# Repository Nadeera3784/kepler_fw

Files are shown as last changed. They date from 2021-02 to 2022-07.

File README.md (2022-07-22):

# F91 Kepler

<p align="center">
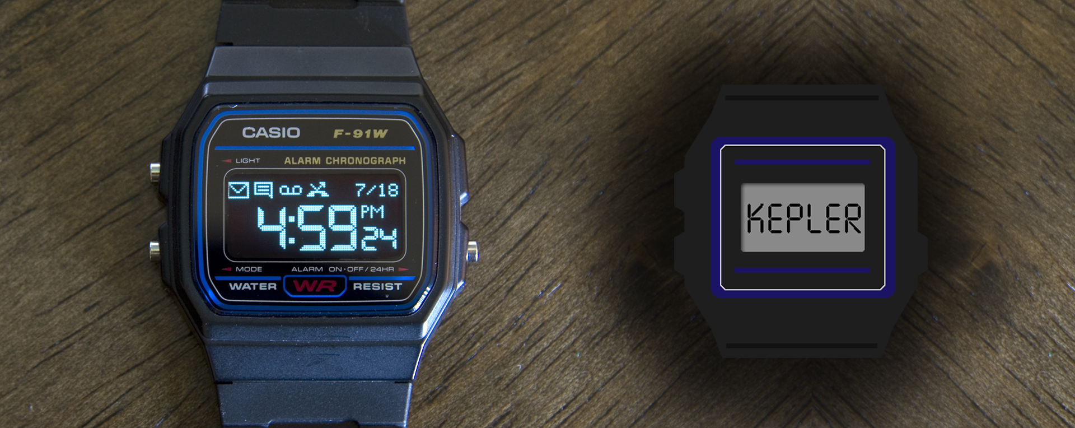
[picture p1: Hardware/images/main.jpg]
  
</p>

The F91 Kepler is complete redesign of the classic Casio F91W watch. This project completely replaces the original internals of the watch only keeping the original case and adding an OLED display and a bluetooth capable MCU.

This repo contains all the firmware, hardware, and completely unfinished software (phone app) ;).

## As of 7/18/22 the current state of the project is:
- Bluetooth capable and supports several calls.
- Only operates through bluetooth diagnostic apps such as nRF Connect.
- Full screen notifications for calls/texts.
- Notifications bar.
- Only one button currently supported to wake screen.
- Battery life of roughly 15 days with waking screen several times a day.

## To-do / improvements:
- Create phone app to handle sending ble calls automatically.
- Add ability to set time through buttons.
- Add sound capabilities. 
- Improve battery life and effiency.
- Improve programming jig (make it easier to do without having to completely dismantle)
- Make rechargeable

### At this point (read more like a year ago) I am burnt out from this project and now I figured to open it up and hopefully more people can be involved.

<p align="center">
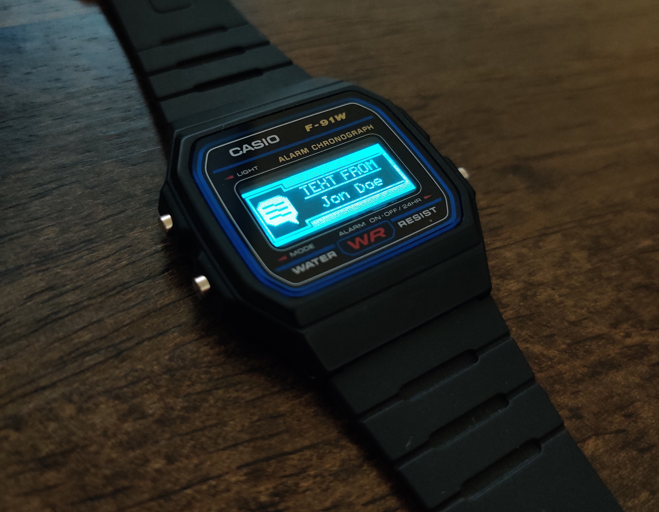
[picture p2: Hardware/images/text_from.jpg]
  
</p>

### Contact
devPegor@gmail.com

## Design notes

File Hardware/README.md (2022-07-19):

# Kepler HW

Found here are the PCB files as well as 3D parts that were made to accommodate this project.

## Main PCB
The PCB was designed using [Diptrace](https://diptrace.com/). The free version was enough for this entire project. The design is not extremely complicated and was based off the development board and design requirements mentioned in the CC2640 Datasheet.

My first design for the board used FPC connectors for the display (4 pin) as well as one for programming/debugging (11 pin). This was later changed to use the Molex board to board connector for the display and small connection points across the PCB for programming/debugging. These changes were made to save room and make it easier to not have to solder and unsolder an FPC connector for programming/debugging. The connection points are hard to see in the real images, but are visible in the render seen in Figure 3 below. The PCB is only two layers and was printed by [OSHPark](https://oshpark.com/) at 0.8mm. This thickness was a little thicker than the original 0.6mm board, but at the price and speed of the service it couldn't be beat. Yes, you can get 0.6mm boards from services such as PCB Way for cheaper, but the shipping costs a ton (at least at this time) and takes forever. The TI design requirements also suggest an 0.8mm board if memory serves me right...

<p align="center">
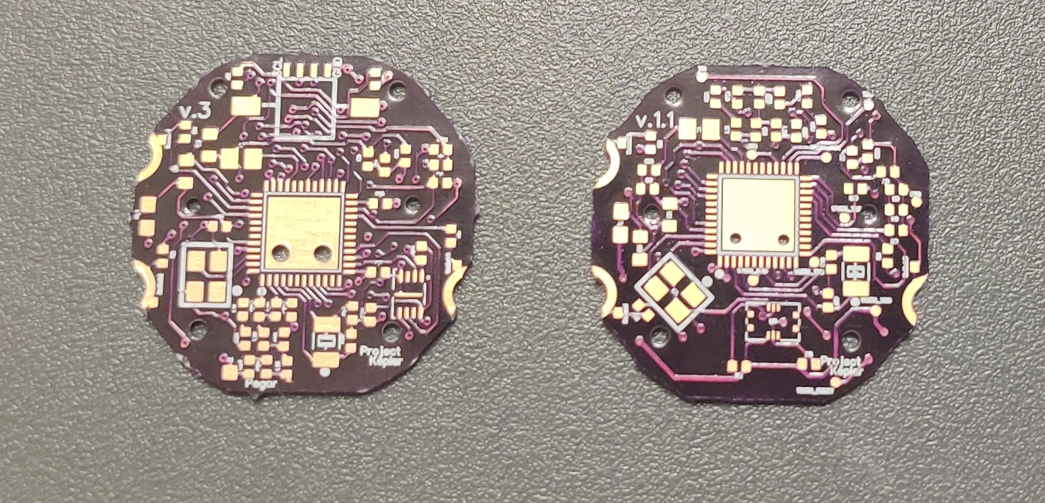
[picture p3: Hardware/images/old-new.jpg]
First & New Design
  
  <br><b>Figure 1</b>: First design on the left and new design on the right.
</p>
<p align="center">
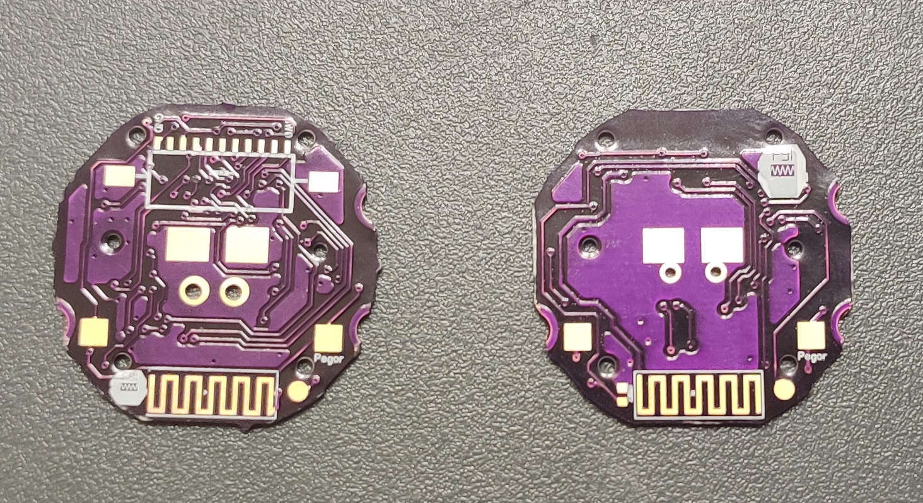
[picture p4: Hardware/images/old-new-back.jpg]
Back of First & New Design
  
  <br><b>Figure 2</b>: Back of first and new design.
</p>

<p align="center">
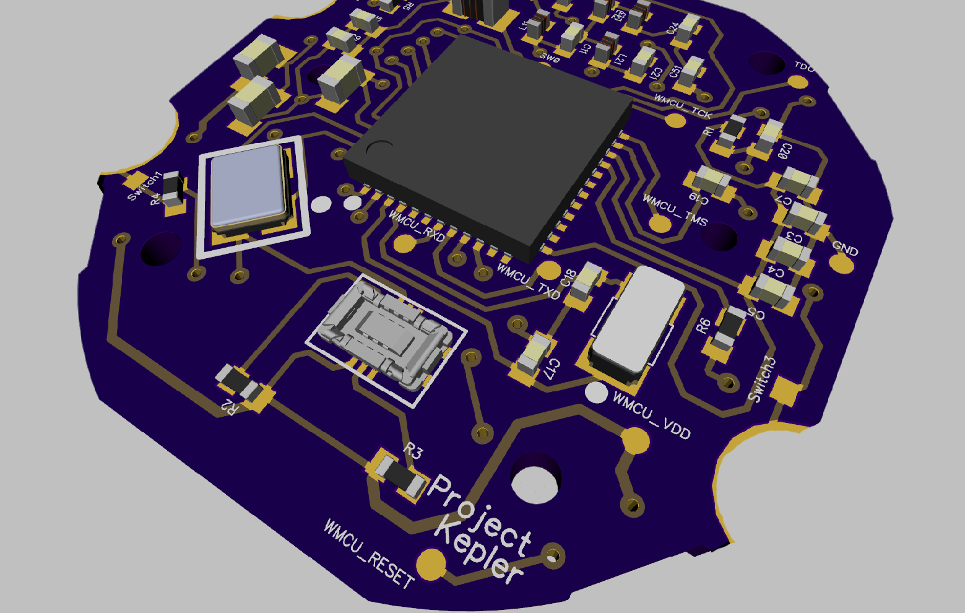
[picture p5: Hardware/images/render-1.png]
PCB Render
  
  <br><b>Figure 3</b>: Render of PCB with connection points visible.
</p>

## Display Adapter
The display adapter was designed to take the 28 pins of the SSD1306 OLED display and bring them down to an easy to use I2C interface. My original design was intended to pair with the FPC connector on the main PCB, but it was too bulky. The second design is much slimmer, easy to manage, and uses a molex board to board connector which so far has worked much better than the FPC connection. One thing to note is that it was an absolute pain to solder those molex connections by hand. 
<p align="center">
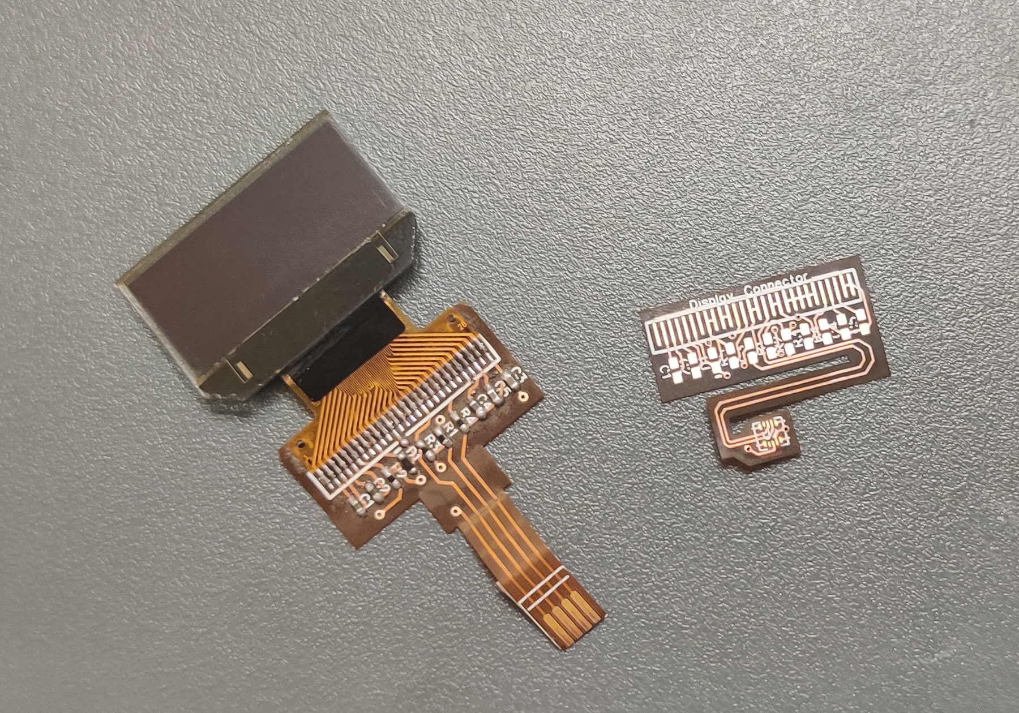
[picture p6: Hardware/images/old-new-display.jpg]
First & New Display Design
  
  <br><b>Figure 4</b>: First display adapter and second design.
</p>

## 3D Parts

### Movement Holder
The original goal for this project was to only change the PCB and display, but the further I got into it the more I realized it's going to be a pain in the ass to use the original movement holder. I tried multiple methods of sanding down and cutting out bits of it, see Figure 5, but it was just a mess and frustrating to work with, so I invested in a resin printer (Hurray, more shit to learn). Once I got a feel for [Fusion 360](https://www.autodesk.com/products/fusion-360), I designed a new movement holder that made life much easier. The new movement holder hugged the PCB perfectly and I was still able to use the original battery clamp, see Figure 9, which made it look so nice! Looking at Figure 6 it's clear how much room I gained from moving away from the original holder. The only part now that was still a little "janky" was that I had to sand down the edges of the SSD1306 Display to make it fit in the case. You can see the sanded rough edges in Figure 8. It's not terrible and much better than murdering the original case, with these changes the case and caseback remained original!

<p align="center">
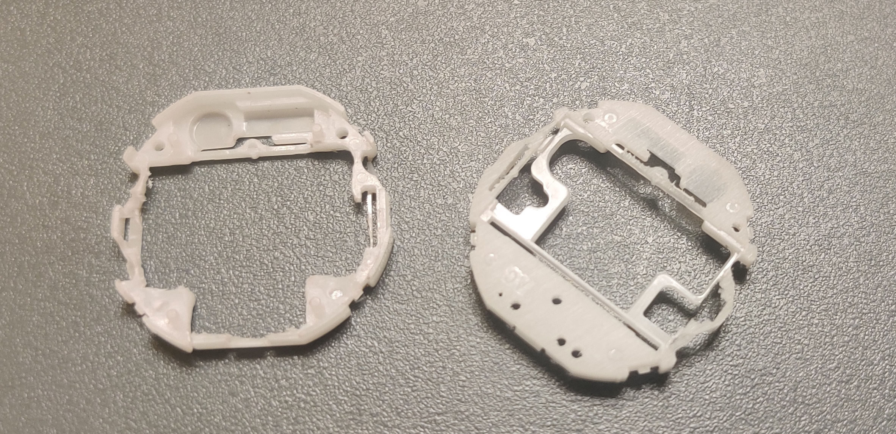
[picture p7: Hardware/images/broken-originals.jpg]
Broken Original Movement Holders
  
  <br><b>Figure 5</b>: Original movement holders.
</p>
<p align="center">
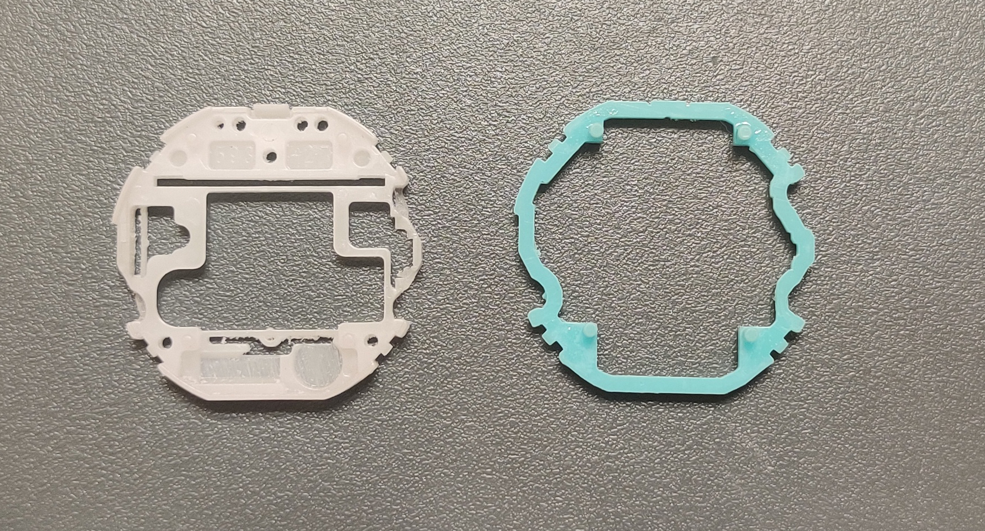
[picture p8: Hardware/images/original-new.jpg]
Original and New Movement Holder
  
  <br><b>Figure 6</b>: Original movement holder on the left and new one on the right.
</p>
<p align="center">
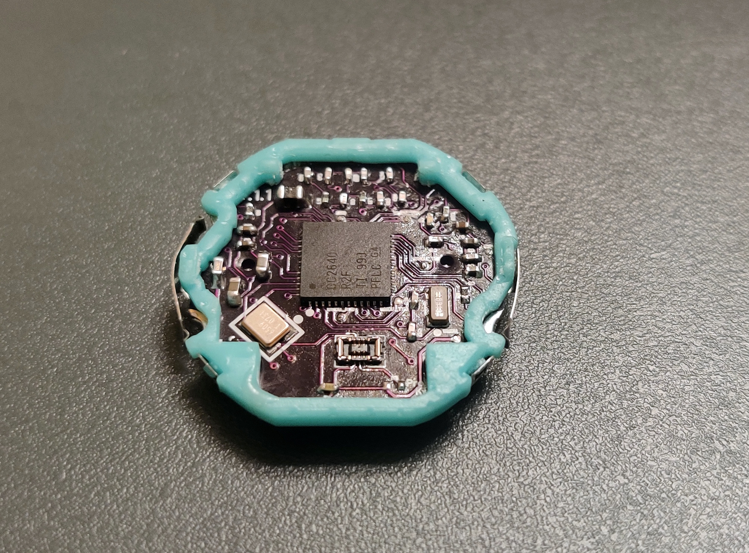
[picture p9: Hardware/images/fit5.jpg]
PCB in Movement Holder
  
  <br><b>Figure 7</b>: PCB sitting perfectly within new movement holder.
</p>
<p align="center">
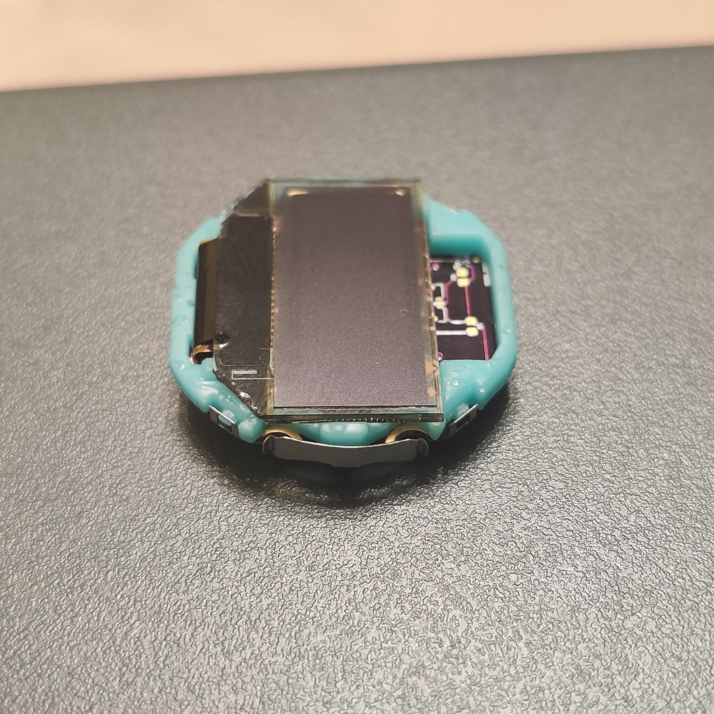
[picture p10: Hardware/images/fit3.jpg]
Display in movement holder
  
  <br><b>Figure 8</b>: Display sitting in new movement holder.
</p>
<p align="center">
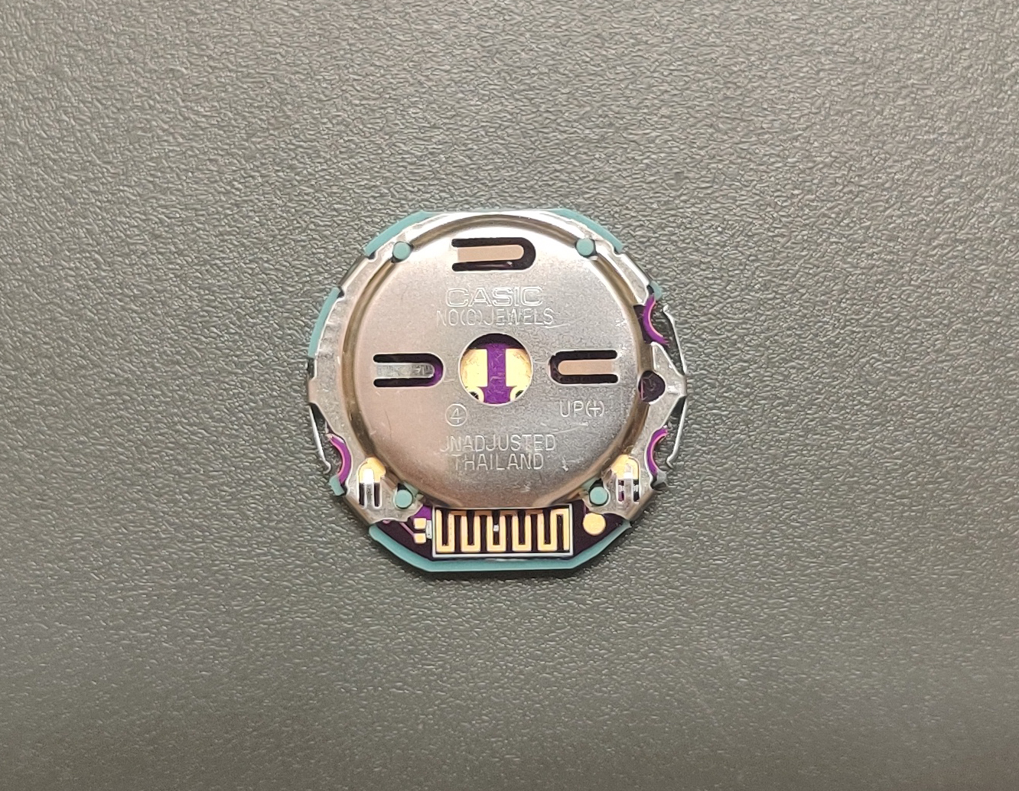
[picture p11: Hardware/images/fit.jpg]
Back of new movement holder
  
  <br><b>Figure 9</b>: Original battery clamp on the new PCB & movement holder.
</p>
<p align="center">
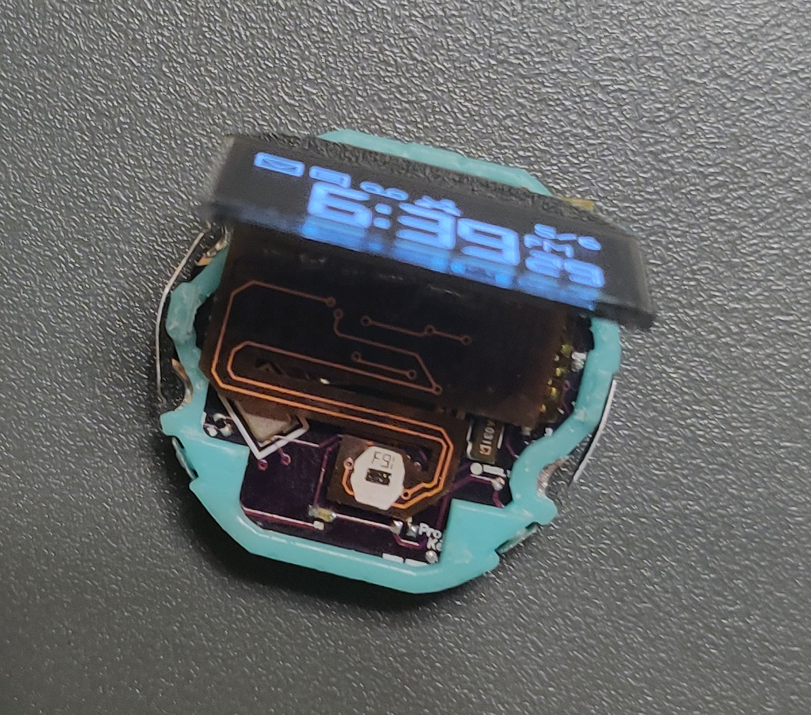
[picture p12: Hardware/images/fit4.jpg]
Display with new movement holder
  
  <br><b>Figure 10</b>: Display connection to the PCB.
</p>
<p align="center">
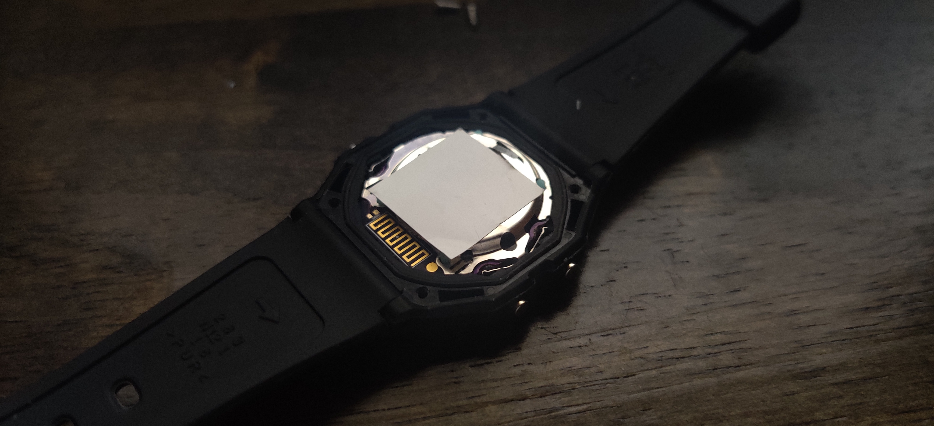
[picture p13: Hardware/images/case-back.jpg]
Case back
  
  <br><b>Figure 11</b>: Perfect fit of the new movement.
</p>

<p align="center">
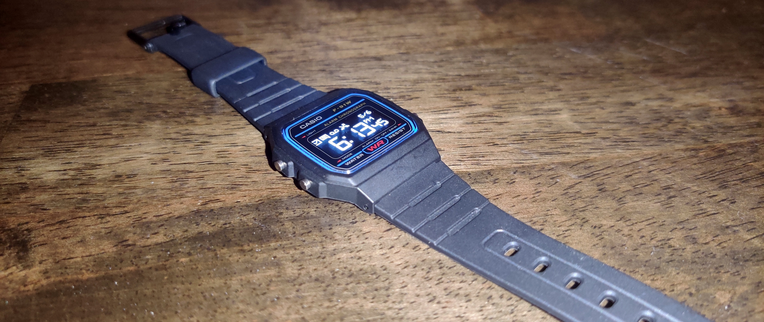
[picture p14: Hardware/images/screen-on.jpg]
Case
  
  <br><b>Figure 12</b>: Completed Build.
</p>

### Programming Jig
Moving away from the 11 pin FPC connector that was on my old design to the new 10 connection points on the PCB meant I needed a jig that can be easily used to program/debug the PCB. My original plan was to use acrylic sheets and dremel some holes in it which would house some tiny pogo pins, but now that I had my hands on a resin printer I designed a jig that can save me a ton of time and look way better than cutting acrylic by hand. The design I came up with can bee seen in Figure 13. It used some [very small spring loaded pogo pings](https://www.amazon.com/gp/product/B08NSKWJTQ/ref=ppx_yo_dt_b_asin_title_o05_s00?ie=UTF8&psc=1) that press against the connection points on the PCB as seen in Figures 14 & 15. This programming jig easily paired with the TI Launchpad and I was able to program the watch from there.

<p align="center">
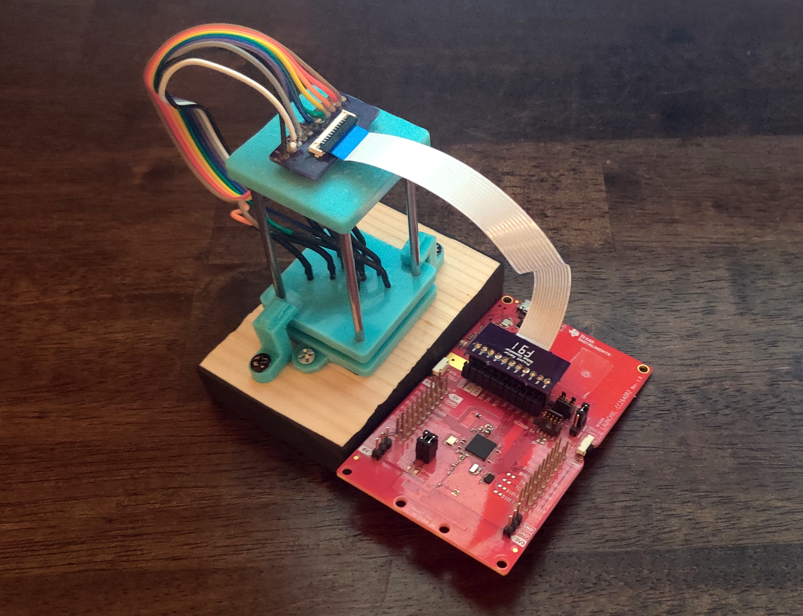
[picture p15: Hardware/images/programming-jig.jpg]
Programming Jig
  
  <br><b>Figure 13</b>: Jig used to program the PCB.
</p>
<p align="center">
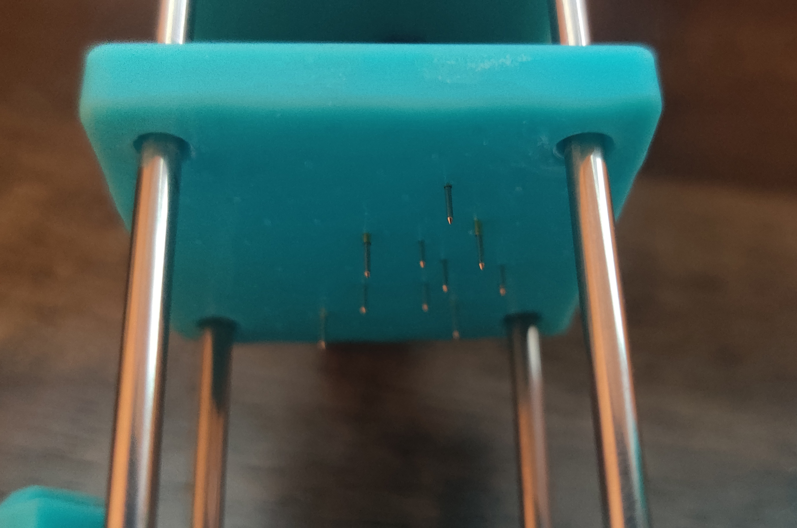
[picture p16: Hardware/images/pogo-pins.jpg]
Pogo pins
  
  <br><b>Figure 14</b>: Tiny spring loaded pogo pins that make the connection to the PCB.
</p>
<p align="center">
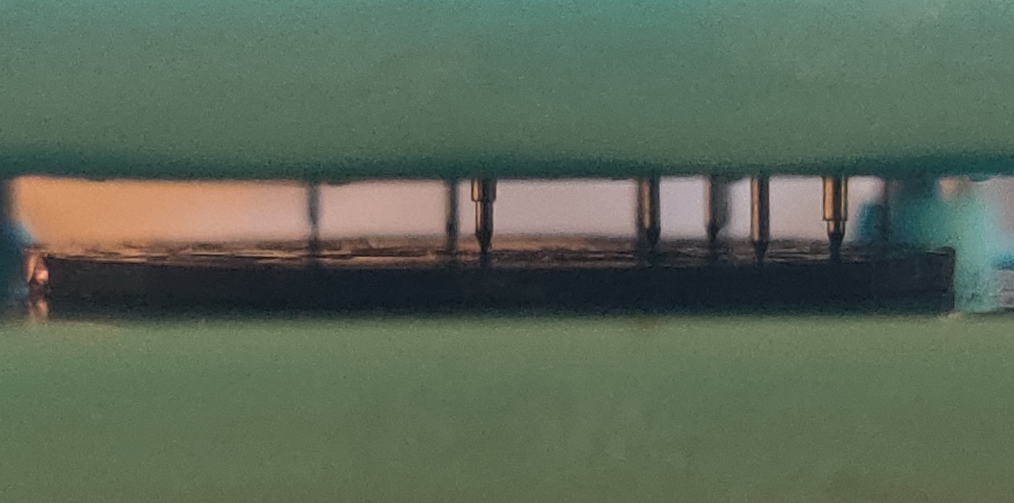
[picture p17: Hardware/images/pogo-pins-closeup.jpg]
Pogo pins
  
  <br><b>Figure 15</b>: Close up of the pogo pins in action.
</p>

## Parts & References
- [SSD1306 0.83" OLED Display](https://www.buydisplay.com/0-83-inch-oled-display-module-spi-ssd1306-controller-blue-on-black-96x39)
- [Pogo Spring Pins (Test Probes)](https://www.amazon.com/gp/product/B08NSKWJTQ/ref=ppx_yo_dt_b_asin_title_o05_s00?ie=UTF8&psc=1)
- [Rods for Programming Jig](https://www.amazon.com/dp/B07KT1N99L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)

- [3D Resin Printer (Elegoo Mars 2)](https://www.amazon.com/ELEGOO-Photocuring-Monochrome-Off-Line-5-1x3-1x5-9in/dp/B08L9JM11J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)

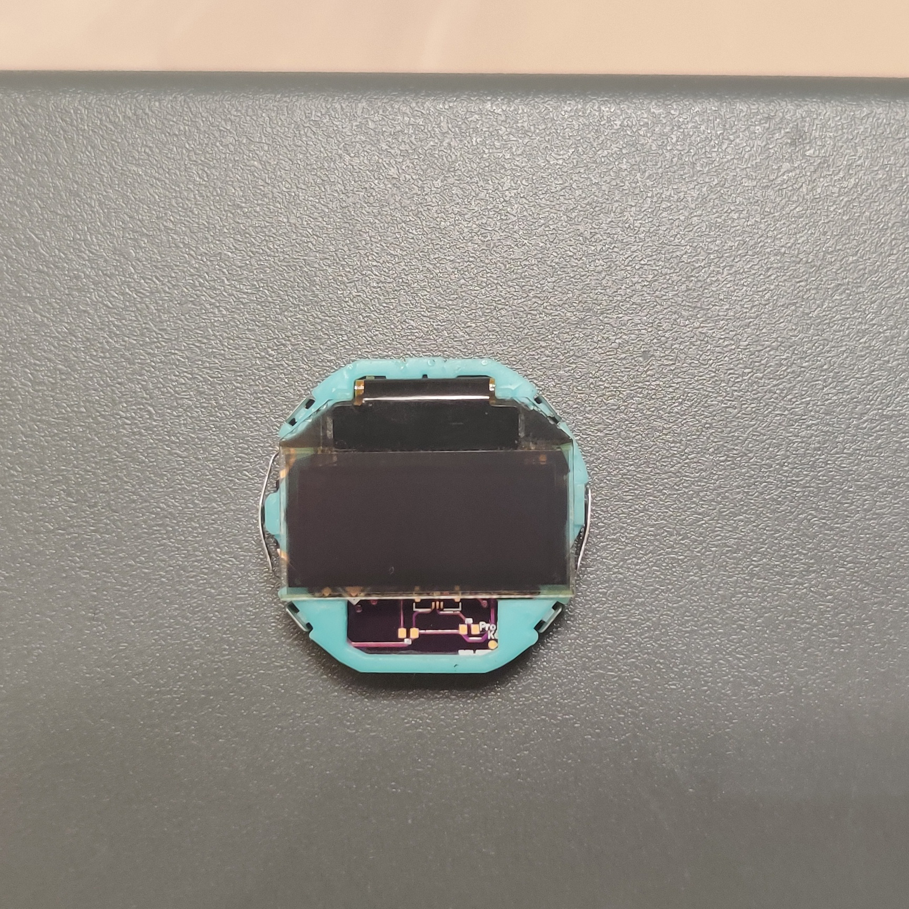
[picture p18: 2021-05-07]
Hardware/images/fit2.jpg

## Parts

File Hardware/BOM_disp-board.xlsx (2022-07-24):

Name | Value | Manufacturer | Quantity | Pattern | Link
CAP_0402 | 1uF |  | 2 | CAP_0402
CAP_0402 | 10uF |  | 1 | CAP_0402
CAP_0402 | 4.7uF |  | 2 | CAP_0402
DIODE_0402 |  |  | 1 | DIO_0402
RES_0402 | 10k |  | 3 | RES_0402
RES_0402 | 390k |  | 1 | RES_0402
RES_0402 | 4.7k |  | 1 | RES_0402
Board to Board & Mezzanine |  | Molex | 1 | 5050700622 | https://www.mouser.com/ProductDetail/538-505070-0622
0.83" OLED Display |  |  | 1 |  | https://www.buydisplay.com/0-83-inch-oled-display-module-spi-ssd1306-controller-blue-on-black-96x39

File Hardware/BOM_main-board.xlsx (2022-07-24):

Name | Value | Manufacturer | Quantity | Pattern | Link
CAP_0402 | 100nF |  | 7 | 402
CAP_0603 | 10uF |  | 2 | 603
CAP_0402 | 1pF |  | 3 | 402
CAP_0402 | 12pF |  | 3 | 402
CAP_0402 | 1uF |  | 1 | 402
CAP_0402 | 6.8pF |  | 1 | 402
CAP_0402 | 1.8pF |  | 1 | 402
Ferrite Bead |  | BLM18HE152SN1 | 1 | 603
IND_0805 | 10uH |  | 1 | 805
IND_0402 | 2.4nH |  | 2 | 402
IND_0402 | 2nH |  | 2 | 402
RES_0402 | 100k |  | 1 | 402
RES_0402 | 3.3k |  | 2 | 402
RES_0402 | 100 |  | 3 | 402
CC2640 |  | Texas Instruments | 1 | RGZ0048A-VQFN-48 | https://www.mouser.com/ProductDetail/595-CC2640R2FRGZR
Board to Board & Mezzanine |  | Molex | 1 | 5050660622 | https://www.digikey.com/en/products/detail/molex/5050660622/9693918
Quartz Oscillator | 32.768kHz | Epson | 1 | FC-135 | https://www.mouser.com/ProductDetail/732-FC135-32.76KAAG0
Quartz Oscillator | 24MHz | Epson | 1 | TSX-3225 | https://www.mouser.com/ProductDetail/732-TX325-24F15X-AC3

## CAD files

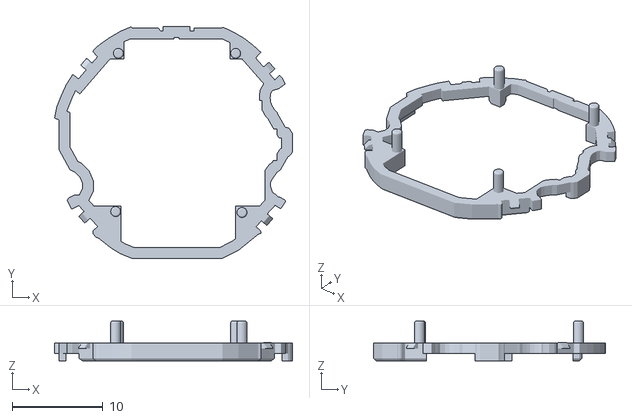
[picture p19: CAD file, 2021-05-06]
Hardware/3D-Parts/F91-Movement_holder.stl
26.2 x 25.5 x 4.40

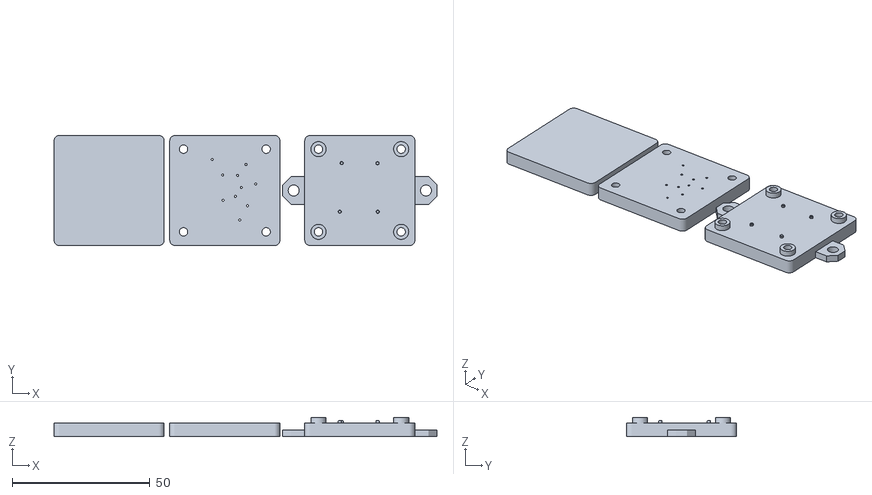
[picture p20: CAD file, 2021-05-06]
Hardware/3D-Parts/F91-Programming_jig.stl
139.0 x 40.0 x 7.00

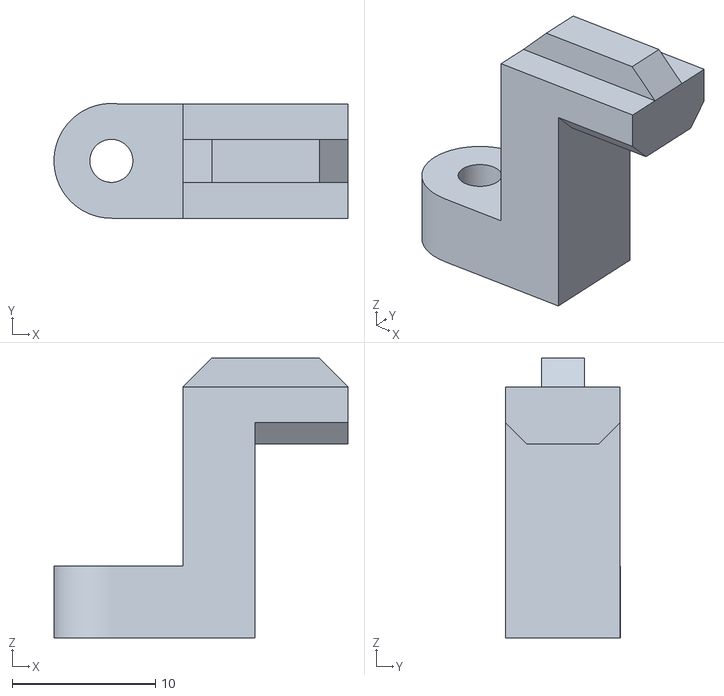
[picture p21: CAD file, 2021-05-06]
Hardware/3D-Parts/F91-Programming_jig_clamps.stl
20.5 x 8.02 x 19.5

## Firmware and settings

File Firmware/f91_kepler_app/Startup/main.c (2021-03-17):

/******************************************************************************

 @file  main.c

 @brief main entry of the BLE stack sample application.

 Group: WCS, BTS
 Target Device: cc2640r2

 ******************************************************************************
 
 Copyright (c) 2013-2021, Texas Instruments Incorporated
 All rights reserved.

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
 *  Neither the name of Texas Instruments Incorporated nor the names of
    its contributors may be used to endorse or promote products derived
    from this software without specific prior written permission.

 THIS SOFTWARE IS PROVIDED BY THE COPYRIGHT HOLDERS AND CONTRIBUTORS "AS IS"
 AND ANY EXPRESS OR IMPLIED WARRANTIES, INCLUDING, BUT NOT LIMITED TO,
 THE IMPLIED WARRANTIES OF MERCHANTABILITY AND FITNESS FOR A PARTICULAR
 PURPOSE ARE DISCLAIMED. IN NO EVENT SHALL THE COPYRIGHT OWNER OR
 CONTRIBUTORS BE LIABLE FOR ANY DIRECT, INDIRECT, INCIDENTAL, SPECIAL,
 EXEMPLARY, OR CONSEQUENTIAL DAMAGES (INCLUDING, BUT NOT LIMITED TO,
 PROCUREMENT OF SUBSTITUTE GOODS OR SERVICES; LOSS OF USE, DATA, OR PROFITS;
 OR BUSINESS INTERRUPTION) HOWEVER CAUSED AND ON ANY THEORY OF LIABILITY,
 WHETHER IN CONTRACT, STRICT LIABILITY, OR TORT (INCLUDING NEGLIGENCE OR
 OTHERWISE) ARISING IN ANY WAY OUT OF THE USE OF THIS SOFTWARE,
 EVEN IF ADVISED OF THE POSSIBILITY OF SUCH DAMAGE.

 ******************************************************************************
 
 
 *****************************************************************************/

/*******************************************************************************
 * INCLUDES
 */


/* XDC module Headers */
#include <xdc/runtime/Error.h>
#include <xdc/std.h>
#include <xdc/runtime/System.h>

#include <ti/drivers/Power.h>
#include <ti/drivers/power/PowerCC26XX.h>
#include <ti/drivers/GPIO.h>
#include <ti/drivers/I2C.h>

#include <ti/sysbios/BIOS.h>
#include <ti/sysbios/knl/Clock.h>
#include <ti/sysbios/knl/Mailbox.h>
#include <ti/display/Display.h>

#include "Board.h"

#include <icall.h>
#include "hal_assert.h"
#include "bcomdef.h"
#include "peripheral.h"
#include "f91_kepler.h"
#include "f91_clock.h"
#include "f91_utils.h"
/* Header files required to enable instruction fetch cache */
#include <inc/hw_memmap.h>
#include <driverlib/vims.h>

#ifndef USE_DEFAULT_USER_CFG

#include "ble_user_config.h"

// BLE user defined configuration
#ifdef ICALL_JT
icall_userCfg_t user0Cfg = BLE_USER_CFG;
#else  /* ! ICALL_JT */
bleUserCfg_t user0Cfg = BLE_USER_CFG;
#endif /* ICALL_JT */

#endif // USE_DEFAULT_USER_CFG

#ifdef USE_FPGA
#include <inc/hw_prcm.h>
#endif // USE_FPGA

/*******************************************************************************
 * MACROS
 */

/*******************************************************************************
 * CONSTANTS
 */

#if defined( USE_FPGA )
  #define RFC_MODE_BLE                 PRCM_RFCMODESEL_CURR_MODE1
  #define RFC_MODE_ANT                 PRCM_RFCMODESEL_CURR_MODE4
  #define RFC_MODE_EVERYTHING_BUT_ANT  PRCM_RFCMODESEL_CURR_MODE5
  #define RFC_MODE_EVERYTHING          PRCM_RFCMODESEL_CURR_MODE6
  //
  #define SET_RFC_BLE_MODE(mode) HWREG( PRCM_BASE + PRCM_O_RFCMODESEL ) = (mode)
#endif // USE_FPGA
/*******************************************************************************
 * TYPEDEFS
 */

/*******************************************************************************
 * LOCAL VARIABLES
 */

/*******************************************************************************
 * GLOBAL VARIABLES
 */
Display_Handle F91_LOGGER = NULL;
Semaphore_Struct semStruct;
Semaphore_Handle semHandle;

/* This buffer is not directly accessed by the application */
MailboxMsgObj mailboxBuffer[NUMMSGS];

Mailbox_Struct mbxStruct;
Mailbox_Handle mbxHandle;

#ifdef CC1350_LAUNCHXL
#ifdef POWER_SAVING
// Power Notify Object for wake-up callbacks
Power_NotifyObj rFSwitchPowerNotifyObj;
static uint8_t rFSwitchNotifyCb(uint8_t eventType, uint32_t *eventArg,
                                uint32_t *clientArg);
#endif //POWER_SAVING

PIN_State  radCtrlState;
PIN_Config radCtrlCfg[] =
{
  Board_DIO1_RFSW   | PIN_GPIO_OUTPUT_EN | PIN_GPIO_LOW  | PIN_PUSHPULL | PIN_DRVSTR_MAX, /* RF SW Switch defaults to 2.4GHz path*/
  Board_DIO30_SWPWR | PIN_GPIO_OUTPUT_EN | PIN_GPIO_HIGH | PIN_PUSHPULL | PIN_DRVSTR_MAX, /* Power to the RF Switch */
  PIN_TERMINATE
};
PIN_Handle radCtrlHandle;
#endif //CC1350_LAUNCHXL

/*******************************************************************************
 * EXTERNS
 */
extern void AssertHandler(uint8 assertCause, uint8 assertSubcause);

/*******************************************************************************
 * @fn          Main
 *
 * @brief       Application Main
 *
 * input parameters
 *
 * @param       None.
 *
 * output parameters
 *
 * @param       None.
 *
 * @return      None.
 */
int main()
{
#if defined( USE_FPGA )
  HWREG(PRCM_BASE + PRCM_O_PDCTL0) &= ~PRCM_PDCTL0_RFC_ON;
  HWREG(PRCM_BASE + PRCM_O_PDCTL1) &= ~PRCM_PDCTL1_RFC_ON;
#endif // USE_FPGA

  /* Register Application callback to trap asserts raised in the Stack */
  RegisterAssertCback(AssertHandler);

  Board_initGeneral();

  GPIO_init();
  I2C_init();

#ifdef CC1350_LAUNCHXL
  // Enable 2.4GHz Radio
  radCtrlHandle = PIN_open(&radCtrlState, radCtrlCfg);

#ifdef POWER_SAVING
  Power_registerNotify(&rFSwitchPowerNotifyObj,
                       PowerCC26XX_ENTERING_STANDBY | PowerCC26XX_AWAKE_STANDBY,
                       (Power_NotifyFxn) rFSwitchNotifyCb, NULL);
#endif //POWER_SAVING
#endif //CC1350_LAUNCHXL

#if defined( USE_FPGA )
  // set RFC mode to support BLE
  // Note: This must be done before the RF Core is released from reset!
  SET_RFC_BLE_MODE(RFC_MODE_BLE);
#endif // USE_FPGA

#ifdef CACHE_AS_RAM
  // retain cache during standby
  Power_setConstraint(PowerCC26XX_SB_VIMS_CACHE_RETAIN);
  Power_setConstraint(PowerCC26XX_NEED_FLASH_IN_IDLE);
#else
  // Enable iCache prefetching
  VIMSConfigure(VIMS_BASE, TRUE, TRUE);
  // Enable cache
  VIMSModeSet(VIMS_BASE, VIMS_MODE_ENABLED);
#endif //CACHE_AS_RAM

#if !defined( POWER_SAVING ) || defined( USE_FPGA )
  /* Set constraints for Standby, powerdown and idle mode */
  // PowerCC26XX_SB_DISALLOW may be redundant
  Power_setConstraint(PowerCC26XX_SB_DISALLOW);
  Power_setConstraint(PowerCC26XX_IDLE_PD_DISALLOW);
#endif // POWER_SAVING | USE_FPGA

#ifdef ICALL_JT
  /* Update User Configuration of the stack */
  user0Cfg.appServiceInfo->timerTickPeriod = Clock_tickPeriod;
  user0Cfg.appServiceInfo->timerMaxMillisecond  = ICall_getMaxMSecs();
#endif  /* ICALL_JT */
  
  //Contrust a mailbox object to be used to communicate across tasks.
  Mailbox_Params mbxParams;
  Mailbox_Params_init(&mbxParams);
  mbxParams.buf = (Ptr)mailboxBuffer;
  mbxParams.bufSize = sizeof(mailboxBuffer);
  Mailbox_construct(&mbxStruct, sizeof(MsgObj), NUMMSGS, &mbxParams, NULL);
  mbxHandle = Mailbox_handle(&mbxStruct);

  /* Construct a Semaphore object to be use as a resource lock, inital count 1 */
  Semaphore_Params semParams;
  Semaphore_Params_init(&semParams);
  Semaphore_construct(&semStruct, 1, &semParams);

    /* Obtain instance handle */
  semHandle = Semaphore_handle(&semStruct);
  
  /* Initialize ICall module */
  ICall_init();

  /* Start tasks of external images - Priority 5 */
  ICall_createRemoteTasks();

  /* Kick off profile - Priority 3 */
  GAPRole_createTask();

  /* Kick off clock application - Priority 2 */
  F91Clock_createTask();

  /* Kick off main smart watch application - Priority 1 */
  F91Kepler_createTask();

  /* enable interrupts and start SYS/BIOS */
  BIOS_start();

  return 0;
}


/*******************************************************************************
 * @fn          AssertHandler
 *
 * @brief       This is the Application's callback handler for asserts raised
 *              in the stack.  When EXT_HAL_ASSERT is defined in the Stack
 *              project this function will be called when an assert is raised,
 *              and can be used to observe or trap a violation from expected
 *              behavior.
 *
 *              As an example, for Heap allocation failures the Stack will raise
 *              HAL_ASSERT_CAUSE_OUT_OF_MEMORY as the assertCause and
 *              HAL_ASSERT_SUBCAUSE_NONE as the assertSubcause.  An application
 *              developer could trap any malloc failure on the stack by calling
 *              HAL_ASSERT_SPINLOCK under the matching case.
 *
 *              An application developer is encouraged to extend this function
 *              for use by their own application.  To do this, add hal_assert.c
 *              to your project workspace, the path to hal_assert.h (this can
 *              be found on the stack side). Asserts are raised by including
 *              hal_assert.h and using macro HAL_ASSERT(cause) to raise an
 *              assert with argument assertCause.  the assertSubcause may be
 *              optionally set by macro HAL_ASSERT_SET_SUBCAUSE(subCause) prior
 *              to asserting the cause it describes. More information is
 *              available in hal_assert.h.
 *
 * input parameters
 *
 * @param       assertCause    - Assert cause as defined in hal_assert.h.
 * @param       assertSubcause - Optional assert subcause (see hal_assert.h).
 *
 * output parameters
 *
 * @param       None.
 *
 * @return      None.
 */
void AssertHandler(uint8 assertCause, uint8 assertSubcause)
{
#if !defined(Display_DISABLE_ALL)
  // Open the display if the app has not already done so
  if ( !F91_LOGGER ) {
    F91_LOGGER = Display_open(Display_Type_UART, NULL);
  }

  Display_print0(F91_LOGGER, 0, 0, ">>>STACK ASSERT");
#endif // ! Display_DISABLE_ALL

  // check the assert cause
  switch (assertCause)
  {
    case HAL_ASSERT_CAUSE_OUT_OF_MEMORY:
#if !defined(Display_DISABLE_ALL)
      Display_print0(F91_LOGGER, 0, 0, "***ERROR***");
      Display_print0(F91_LOGGER, 2, 0, ">> OUT OF MEMORY!");
#endif // ! Display_DISABLE_ALL
      break;

    case HAL_ASSERT_CAUSE_INTERNAL_ERROR:
      // check the subcause
      if (assertSubcause == HAL_ASSERT_SUBCAUSE_FW_INERNAL_ERROR)
      {
#if !defined(Display_DISABLE_ALL)
        Display_print0(F91_LOGGER, 0, 0, "***ERROR***");
        Display_print0(F91_LOGGER, 2, 0, ">> INTERNAL FW ERROR!");
#endif // ! Display_DISABLE_ALL
      }
      else
      {
#if !defined(Display_DISABLE_ALL)
        Display_print0(F91_LOGGER, 0, 0, "***ERROR***");
        Display_print0(F91_LOGGER, 2, 0, ">> INTERNAL ERROR!");
#endif // ! Display_DISABLE_ALL
      }
      break;

    case HAL_ASSERT_CAUSE_ICALL_ABORT:
#if !defined(Display_DISABLE_ALL)
      Display_print0(F91_LOGGER, 0, 0, "***ERROR***");
      Display_print0(F91_LOGGER, 2, 0, ">> ICALL ABORT!");
#endif // ! Display_DISABLE_ALL
      HAL_ASSERT_SPINLOCK;
      break;

    case HAL_ASSERT_CAUSE_ICALL_TIMEOUT:
#if !defined(Display_DISABLE_ALL)
      Display_print0(F91_LOGGER, 0, 0, "***ERROR***");
      Display_print0(F91_LOGGER, 2, 0, ">> ICALL TIMEOUT!");
#endif // ! Display_DISABLE_ALL
      HAL_ASSERT_SPINLOCK;
      break;

    case HAL_ASSERT_CAUSE_WRONG_API_CALL:
#if !defined(Display_DISABLE_ALL)
      Display_print0(F91_LOGGER, 0, 0, "***ERROR***");
      Display_print0(F91_LOGGER, 2, 0, ">> WRONG API CALL!");
#endif // ! Display_DISABLE_ALL
      HAL_ASSERT_SPINLOCK;
      break;

  default:
#if !defined(Display_DISABLE_ALL)
      Display_print0(F91_LOGGER, 0, 0, "***ERROR***");
      Display_print0(F91_LOGGER, 2, 0, ">> DEFAULT SPINLOCK!");
#endif // ! Display_DISABLE_ALL
      HAL_ASSERT_SPINLOCK;
  }

  return;
}


/*******************************************************************************
 * @fn          smallErrorHook
 *
 * @brief       Error handler to be hooked into TI-RTOS.
 *
 * input parameters
 *
 * @param       eb - Pointer to Error Block.
 *
 * output parameters
 *
 * @param       None.
 *
 * @return      None.
 */
void smallErrorHook(Error_Block *eb)
{
  for (;;);
}

#if defined (CC1350_LAUNCHXL) && defined (POWER_SAVING)
/*******************************************************************************
 * @fn          rFSwitchNotifyCb
 *
 * @brief       Power driver callback to toggle RF switch on Power state
 *              transitions.
 *
 * input parameters
 *
 * @param   eventType - The state change.
 * @param   eventArg  - Not used.
 * @param   clientArg - Not used.
 *
 * @return  Power_NOTIFYDONE to indicate success.
 */
static uint8_t rFSwitchNotifyCb(uint8_t eventType, uint32_t *eventArg,
                                uint32_t *clientArg)
{
  if (eventType == PowerCC26XX_ENTERING_STANDBY)
  {
    // Power down RF Switch
    PIN_setOutputValue(radCtrlHandle, Board_DIO30_SWPWR, 0);
  }
  else if (eventType == PowerCC26XX_AWAKE_STANDBY)
  {
    // Power up RF Switch
    PIN_setOutputValue(radCtrlHandle, Board_DIO30_SWPWR, 1);
  }

  // Notification handled successfully
  return Power_NOTIFYDONE;
}
#endif //CC1350_LAUNCHXL || POWER_SAVING


/*******************************************************************************
 */

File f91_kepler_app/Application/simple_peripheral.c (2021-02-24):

/******************************************************************************

 @file  simple_peripheral.c

 @brief This file contains the Simple Peripheral sample application for use
        with the CC2650 Bluetooth Low Energy Protocol Stack.

 Group: WCS, BTS
 Target Device: cc2640r2

 ******************************************************************************
 
 Copyright (c) 2013-2021, Texas Instruments Incorporated
 All rights reserved.

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
 *  Neither the name of Texas Instruments Incorporated nor the names of
    its contributors may be used to endorse or promote products derived
    from this software without specific prior written permission.

 THIS SOFTWARE IS PROVIDED BY THE COPYRIGHT HOLDERS AND CONTRIBUTORS "AS IS"
 AND ANY EXPRESS OR IMPLIED WARRANTIES, INCLUDING, BUT NOT LIMITED TO,
 THE IMPLIED WARRANTIES OF MERCHANTABILITY AND FITNESS FOR A PARTICULAR
 PURPOSE ARE DISCLAIMED. IN NO EVENT SHALL THE COPYRIGHT OWNER OR
 CONTRIBUTORS BE LIABLE FOR ANY DIRECT, INDIRECT, INCIDENTAL, SPECIAL,
 EXEMPLARY, OR CONSEQUENTIAL DAMAGES (INCLUDING, BUT NOT LIMITED TO,
 PROCUREMENT OF SUBSTITUTE GOODS OR SERVICES; LOSS OF USE, DATA, OR PROFITS;
 OR BUSINESS INTERRUPTION) HOWEVER CAUSED AND ON ANY THEORY OF LIABILITY,
 WHETHER IN CONTRACT, STRICT LIABILITY, OR TORT (INCLUDING NEGLIGENCE OR
 OTHERWISE) ARISING IN ANY WAY OUT OF THE USE OF THIS SOFTWARE,
 EVEN IF ADVISED OF THE POSSIBILITY OF SUCH DAMAGE.

 ******************************************************************************
 
 
 *****************************************************************************/

/*********************************************************************
 * INCLUDES
 */
#include <string.h>

#include <ti/sysbios/knl/Task.h>
#include <ti/sysbios/knl/Clock.h>
#include <ti/sysbios/knl/Event.h>
#include <ti/sysbios/knl/Queue.h>
#include <ti/display/Display.h>

#if defined( USE_FPGA ) || defined( DEBUG_SW_TRACE )
#include <driverlib/ioc.h>
#endif // USE_FPGA | DEBUG_SW_TRACE

#include <icall.h>
#include "util.h"
#include "att_rsp.h"

/* This Header file contains all BLE API and icall structure definition */
#include "icall_ble_api.h"

#include "devinfoservice.h"
#include "simple_gatt_profile.h"
#include "ll_common.h"

#include "peripheral.h"

#ifdef USE_RCOSC
#include "rcosc_calibration.h"
#endif //USE_RCOSC

#include "board_key.h"

#include "board.h"

#include "simple_peripheral.h"

/*********************************************************************
 * CONSTANTS
 */

// Advertising interval when device is discoverable (units of 625us, 160=100ms)
#define DEFAULT_ADVERTISING_INTERVAL          160

// General discoverable mode: advertise indefinitely
#define DEFAULT_DISCOVERABLE_MODE             GAP_ADTYPE_FLAGS_GENERAL

// Minimum connection interval (units of 1.25ms, 80=100ms) for automatic
// parameter update request
#define DEFAULT_DESIRED_MIN_CONN_INTERVAL     80

// Maximum connection interval (units of 1.25ms, 800=1000ms) for automatic
// parameter update request
#define DEFAULT_DESIRED_MAX_CONN_INTERVAL     800

// Slave latency to use for automatic parameter update request
#define DEFAULT_DESIRED_SLAVE_LATENCY         0

// Supervision timeout value (units of 10ms, 1000=10s) for automatic parameter
// update request
#define DEFAULT_DESIRED_CONN_TIMEOUT          1000

// After the connection is formed, the peripheral waits until the central
// device asks for its preferred connection parameters
#define DEFAULT_ENABLE_UPDATE_REQUEST         GAPROLE_LINK_PARAM_UPDATE_WAIT_REMOTE_PARAMS

// Connection Pause Peripheral time value (in seconds)
#define DEFAULT_CONN_PAUSE_PERIPHERAL         6

// How often to perform periodic event (in msec)
#define SBP_PERIODIC_EVT_PERIOD               5000

// Application specific event ID for HCI Connection Event End Events
#define SBP_HCI_CONN_EVT_END_EVT              0x0001

// Type of Display to open
#if !defined(Display_DISABLE_ALL)
  #if defined(BOARD_DISPLAY_USE_LCD) && (BOARD_DISPLAY_USE_LCD!=0)
    #define SBP_DISPLAY_TYPE Display_Type_LCD
  #elif defined (BOARD_DISPLAY_USE_UART) && (BOARD_DISPLAY_USE_UART!=0)
    #define SBP_DISPLAY_TYPE Display_Type_UART
  #else // !BOARD_DISPLAY_USE_LCD && !BOARD_DISPLAY_USE_UART
    #define SBP_DISPLAY_TYPE 0 // Option not supported
  #endif // BOARD_DISPLAY_USE_LCD && BOARD_DISPLAY_USE_UART
#else // BOARD_DISPLAY_USE_LCD && BOARD_DISPLAY_USE_UART
  #define SBP_DISPLAY_TYPE 0 // No Display
#endif // !Display_DISABLE_ALL

// Task configuration
#define SBP_TASK_PRIORITY                     1

#ifndef SBP_TASK_STACK_SIZE
#define SBP_TASK_STACK_SIZE                   644
#endif

// Application events
#define SBP_STATE_CHANGE_EVT                  0x0001
#define SBP_CHAR_CHANGE_EVT                   0x0002
#define SBP_PAIRING_STATE_EVT                 0x0004
#define SBP_PASSCODE_NEEDED_EVT               0x0008
#define SBP_CONN_EVT                          0x0010

// Internal Events for RTOS application
#define SBP_ICALL_EVT                         ICALL_MSG_EVENT_ID // Event_Id_31
#define SBP_QUEUE_EVT                         UTIL_QUEUE_EVENT_ID // Event_Id_30
#define SBP_PERIODIC_EVT                      Event_Id_00

// Bitwise OR of all events to pend on
#define SBP_ALL_EVENTS                        (SBP_ICALL_EVT        | \
                                               SBP_QUEUE_EVT        | \
                                               SBP_PERIODIC_EVT)


// Set the register cause to the registration bit-mask
#define CONNECTION_EVENT_REGISTER_BIT_SET(RegisterCause) (connectionEventRegisterCauseBitMap |= RegisterCause )
// Remove the register cause from the registration bit-mask
#define CONNECTION_EVENT_REGISTER_BIT_REMOVE(RegisterCause) (connectionEventRegisterCauseBitMap &= (~RegisterCause) )
// Gets whether the current App is registered to the receive connection events
#define CONNECTION_EVENT_IS_REGISTERED (connectionEventRegisterCauseBitMap > 0)
// Gets whether the RegisterCause was registered to recieve connection event
#define CONNECTION_EVENT_REGISTRATION_CAUSE(RegisterCause) (connectionEventRegisterCauseBitMap & RegisterCause )

/*********************************************************************
 * TYPEDEFS
 */

// App event passed from profiles.
typedef struct
{
  appEvtHdr_t hdr;  // event header.
  uint8_t *pData;  // event data
} sbpEvt_t;

/*********************************************************************
 * GLOBAL VARIABLES
 */

// Display Interface
Display_Handle dispHandle = NULL;

/*********************************************************************
 * LOCAL VARIABLES
 */

// Entity ID globally used to check for source and/or destination of messages
static ICall_EntityID selfEntity;

// Event globally used to post local events and pend on system and
// local events.
static ICall_SyncHandle syncEvent;

// Clock instances for internal periodic events.
static Clock_Struct periodicClock;
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

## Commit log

2021-02-24 Add ignore files
    [ECCROMCC26XX.obj, RFCC26XX_singleMode.obj, TRNGCC26XX.obj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]
2021-03-02 Renaming + added ssd1306 driver + cleanup
2021-03-06 These files are generated at build time. Removed.
    [m3_Hwi_asm.obj, m3_Hwi_asm_switch.obj, m3_IntrinsicsSupport_asm.obj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]
2021-03-08 Added Clock Task
    [app_ble.cfg]
2021-03-12 Clean up SSD1306 driver code & add button logic
2021-03-14 Move buttons init & handling out of Kepler
2021-05-06 Change buttons to match new board
2021-05-06 Repo Restructure
    [app_ble.cfg]
2021-05-06 Adding PCB and 3D Parts
    [F91-Movement_holder.stl, F91-Programming_jig.stl, F91-Programming_jig_clamps.stl]
2021-08-21 Add ifdef for dev board
2022-07-24 Upload main board BOM
    [BOM_main-board.xlsx]
2022-07-24 Upload displ connector BOM
    [BOM_disp-board.xlsx]
